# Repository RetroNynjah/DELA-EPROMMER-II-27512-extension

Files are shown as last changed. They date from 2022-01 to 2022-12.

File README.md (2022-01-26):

# DELA-EPROMMER-II 27512 Extension
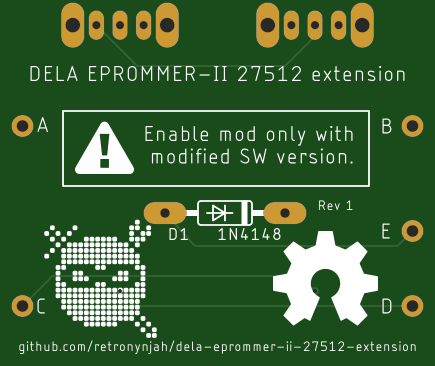
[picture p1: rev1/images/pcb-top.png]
PCB


## Background 
This is a reproduction of the 27512 extension board from DELA-Elektronik for the DELA-EPROMMER II for the Commodore 64.  
The user instruction calls this add-on "Umbauset für den DELA-EPROMMER II"

This extension makes it possible to program 27512 EPROMS with the DELA-EPROMMER II by removing VPP from pin 1 and replacing it with the switch controlled address pin A15. A special version of the DELA EPROMMER software is needed which connects VPP to pin 22. This special version is available in the software folder.
The 27512 has to be programmed in two 32kB passes and there are two switches on the board, one for activation/deactivation of the extension and one for 32kB block selection (A15).

When this extension is active, the EPROMMER should only be used with a special version of the DELA EPROMMER software. If the extension is deactivated by the switch, it can be used with the standard software.
A scan of the orginal German user manual for the extension was posted in [this forum thread](https://www.forum64.de/index.php?thread/109845-dela-ii-brenner-mit-zusatzplatine/). There's also a copy in the docs folder.

## Installation instruction
Follow the german user instruction in the docs folder or:

* Remove the diode that is located close to the ZIF socket and the LED. That diode is called D1 on Dirk's reproduction PCB.
* Solder points A,B,C,D on the extensions to the four corner pins of the ZIF socket on the bottom side of the board.
* Wire point E on the extension board to where the anode side of the diode was connected. See photos below or the original instruction in the docs folder.

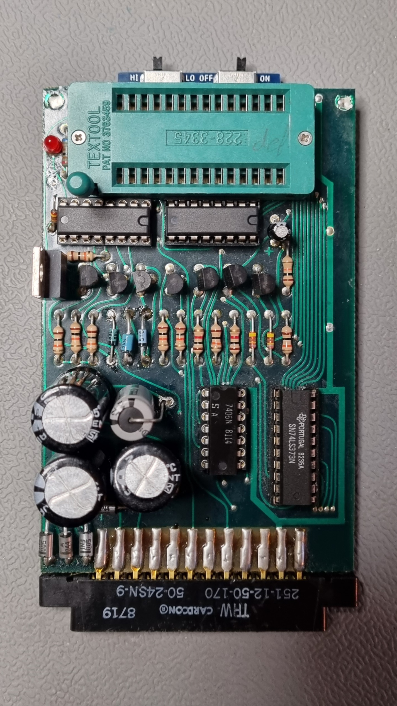
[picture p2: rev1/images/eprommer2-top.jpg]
top
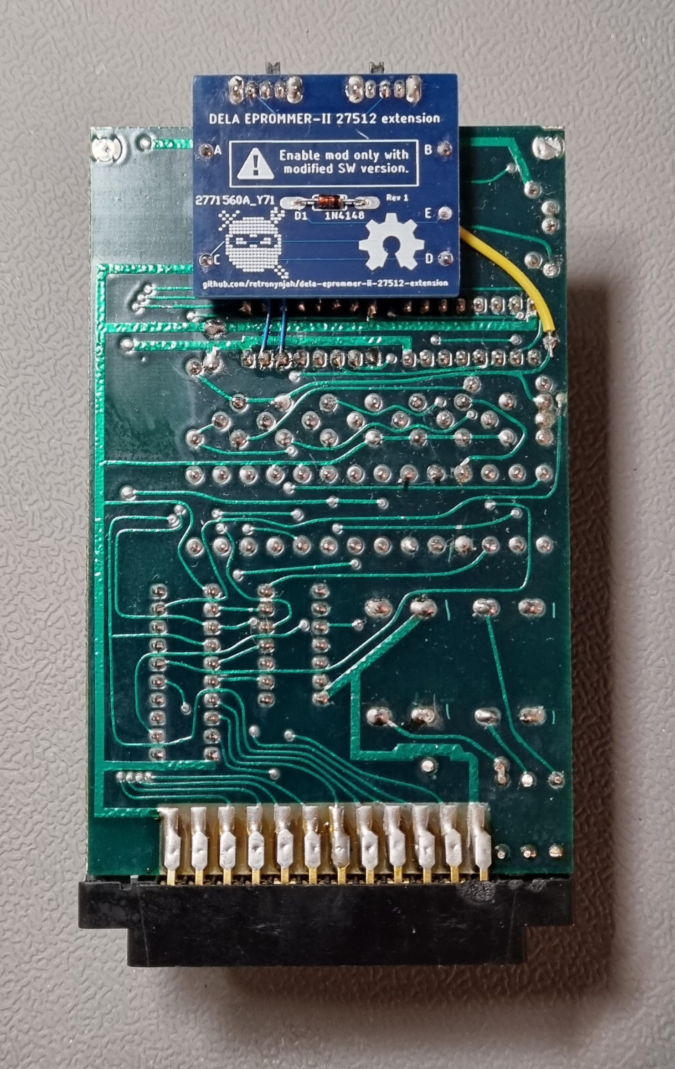
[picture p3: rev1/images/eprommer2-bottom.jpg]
bottom

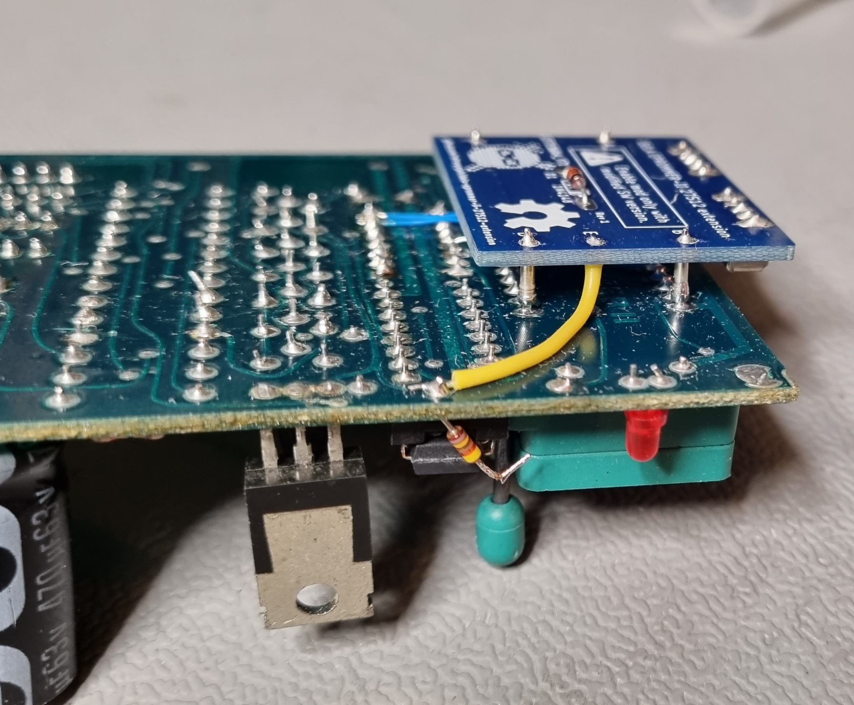
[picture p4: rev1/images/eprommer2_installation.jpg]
installation


The part count fort this build is low.
The two slide switches in the design are different from the ones on the original extension because silde switches with that pitch can't be found anymore.  
The ones I used are right-angle switches with a 2mm pitch and has solder connections for the metal frame to add stability. I used a cheap TE switch with part number 1825232-1 which can be found at Digikey with part number A107673-ND.  
The diode is a 1N4148.  
The posts that I use to connect the extension to the pins on bottom of the ZIF-socket are four pins that I pulled out of an IC socket with machined (round) pins. They can usually be grabbed with pliers and pushed out of the socket.

## Usage
**Warning!** Activate the exetension only together with the modified software.

The EPROM has to be programmed in two halved because a full 64kB EPROM image can't fit in RAM so you need to split your ROM file in two halves before programming.

To burn a 27512 EPROM:
* Activate the extension by setting the right switch to the ON position.
* Fire up the custom 512kbit version of the EPROMMER-II application
* Insert EPROM to be programmed.
* Load one half of the 64KByte ROM you want to program.
* Use the left slide switch to select which half you want to program
* Go into the EPROM programming menu and program as usual but select the invisible 6th option (27512) when selecting EPROM type.
* Repeat procedure for the next half of the EPROM

Dirk Wouters has created a reproduction of the complete DELA-EPROMMER II which together with schematics, user manuals and standard software can be found at https://github.com/DL2DW/DELA-EPROMMER-II

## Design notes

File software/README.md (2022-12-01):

# Software
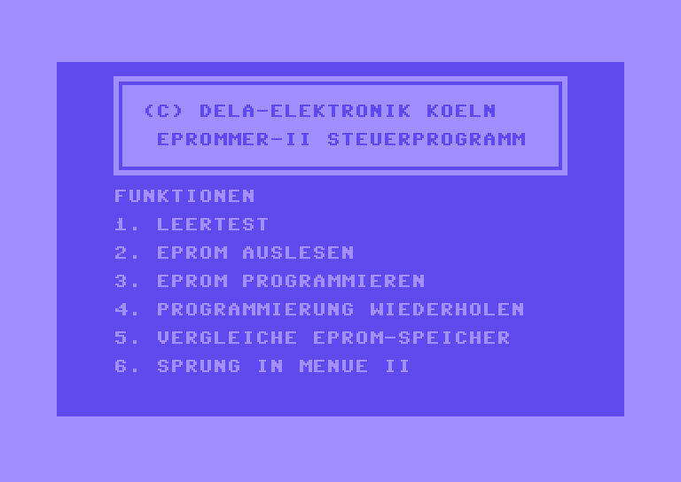
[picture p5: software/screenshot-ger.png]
PCB


This directory contains the original German version of the special 512kbit version of the EPROMMER software.

It also contains an archive with English versions translated by [giobbino](https://github.com/giobbino). Thank you!
The archive contains English translations of both the standard version of the software and the 512kbit version as well as translated user instructions. Everyone is welcome to improve the translations.

The English software along with some other tools now has an own repository at https://github.com/giobbino/DELA-Eprommer-II-ENG-software-for-Commodore-64

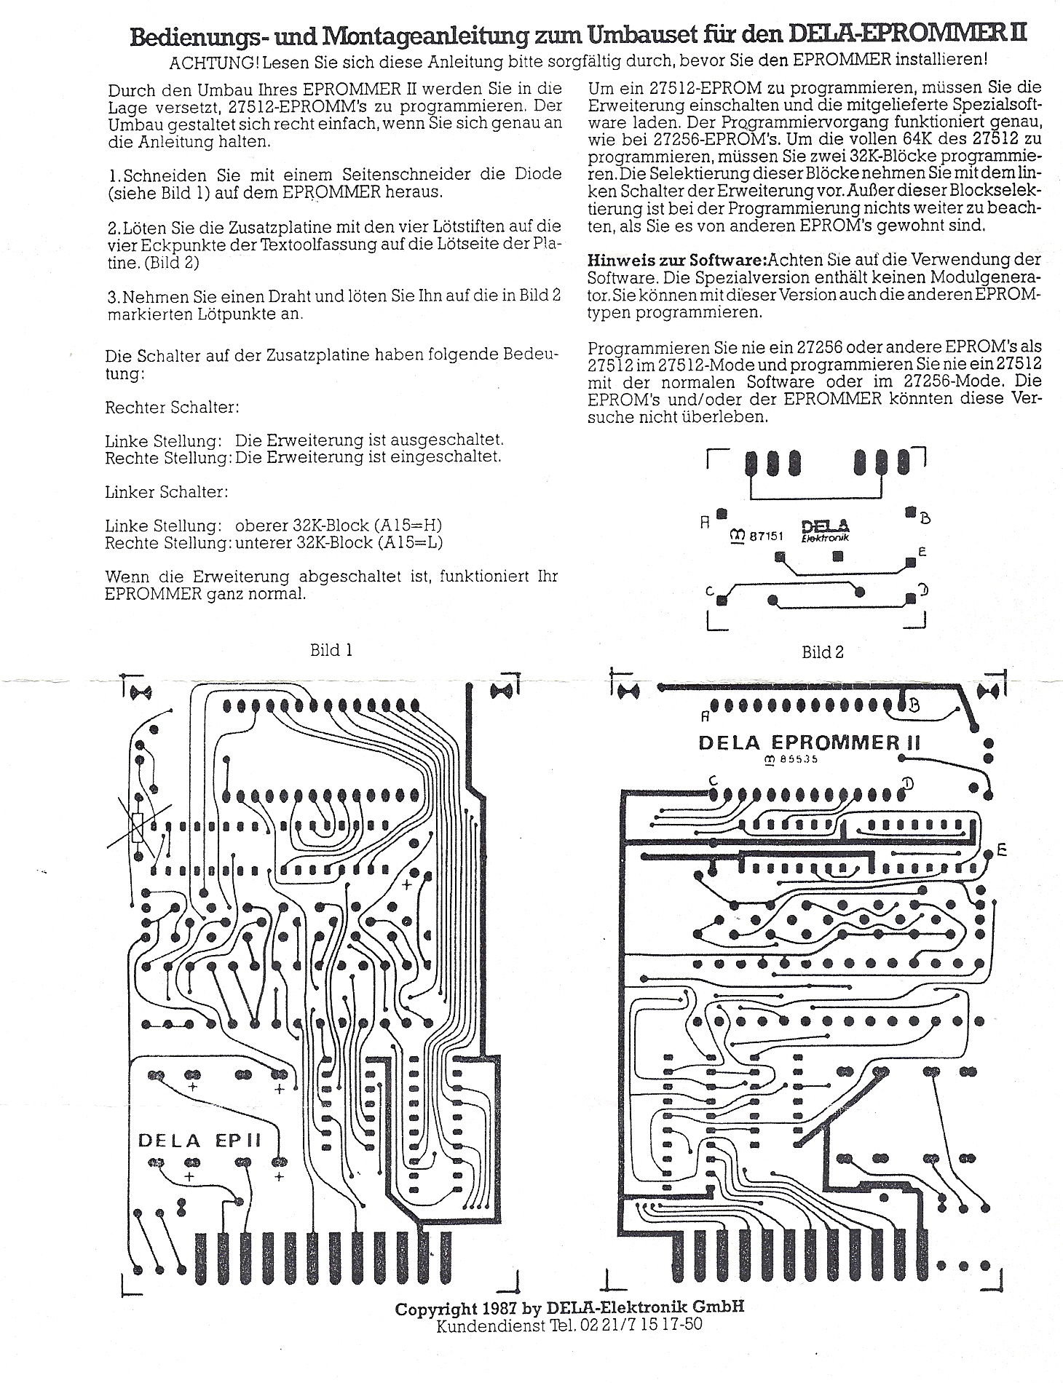
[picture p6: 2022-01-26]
docs/DELA2-Umbau512.jpg

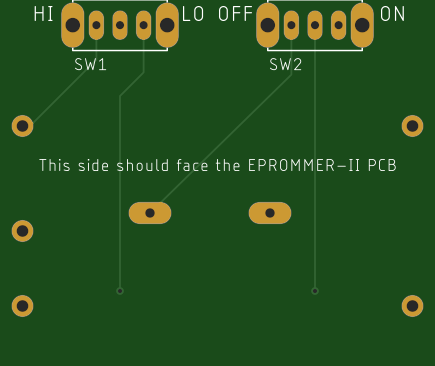
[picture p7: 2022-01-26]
rev1/images/pcb-bottom.png

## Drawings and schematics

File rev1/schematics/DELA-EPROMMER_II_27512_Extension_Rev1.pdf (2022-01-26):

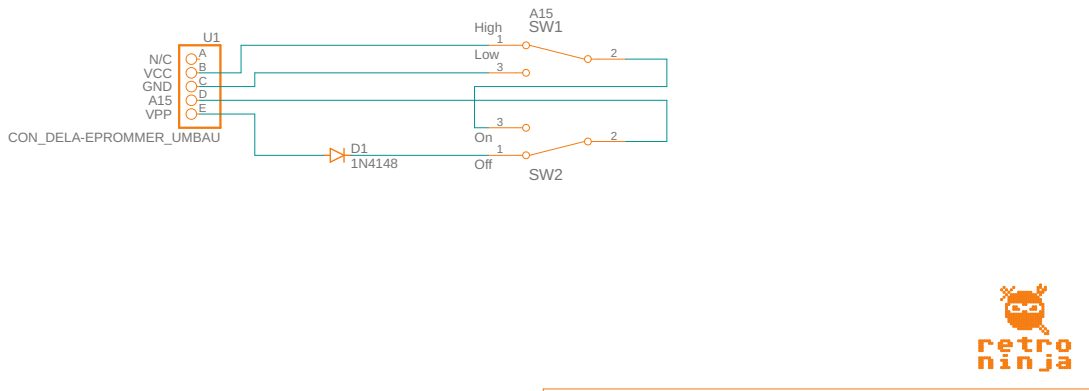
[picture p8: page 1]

DELA-EPROMMER II 27512 Extension

Document Number: | REV: 1

Date: 2021-12-23 | Sheet: 1/1

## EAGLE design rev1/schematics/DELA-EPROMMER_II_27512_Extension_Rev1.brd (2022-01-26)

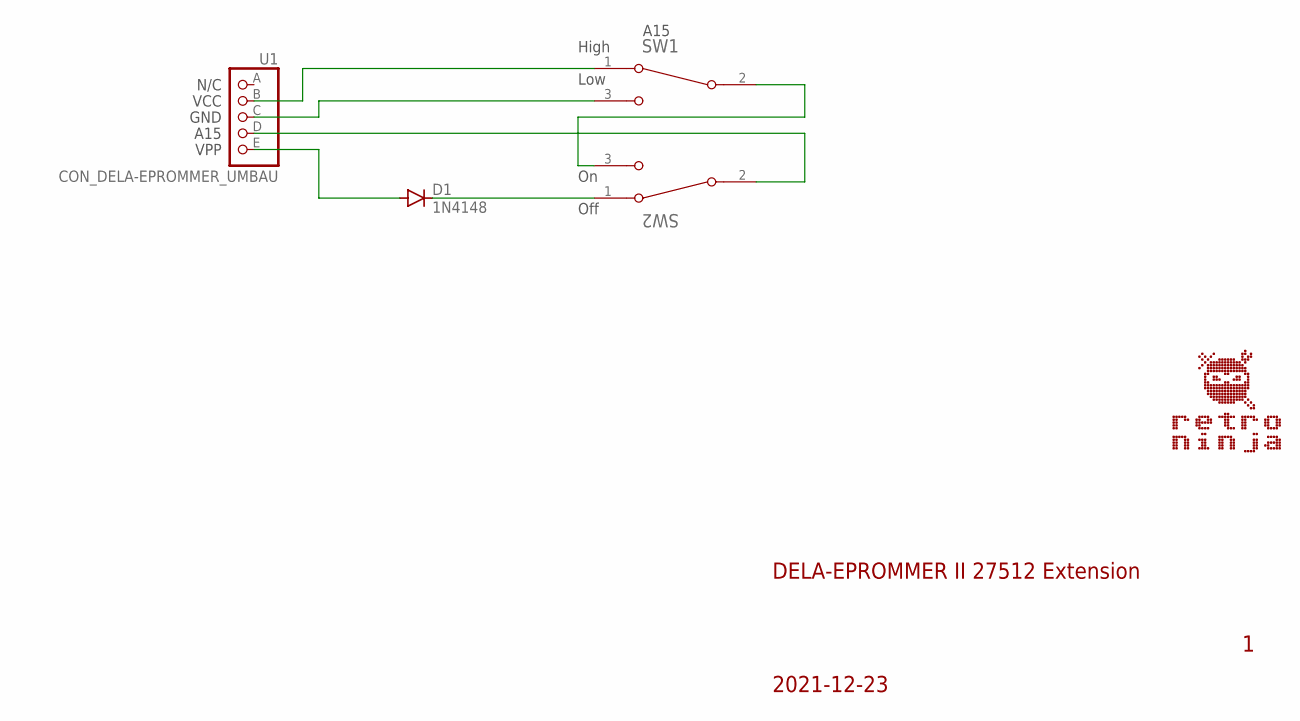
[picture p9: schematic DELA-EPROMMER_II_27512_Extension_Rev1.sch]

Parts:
D1: 1N4148; DO35-10
SW1, SW2: SWITCH_SLIDE_2POS_2MM
U1: CON_DELA-EPROMMER_UMBAU

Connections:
unnamed: SW1.1, U1.B
unnamed: SW1.3, U1.C
unnamed: SW2.2, U1.D
unnamed: SW1.2, SW2.3
unnamed: D1.C, SW2.1
unnamed: D1.A, U1.E

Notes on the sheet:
N/C
VCC
GND
A15
VPP
High
Low
Off
2021-12-23
DELA-EPROMMER II 27512 Extension

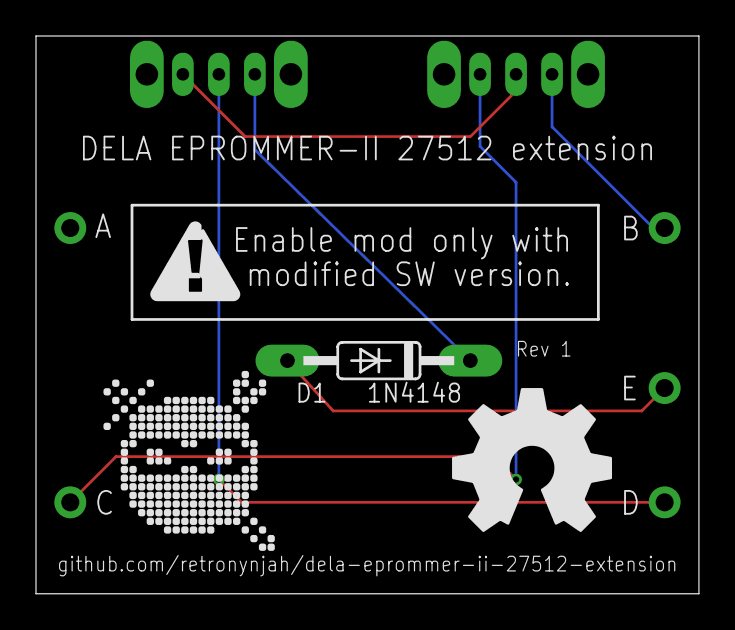
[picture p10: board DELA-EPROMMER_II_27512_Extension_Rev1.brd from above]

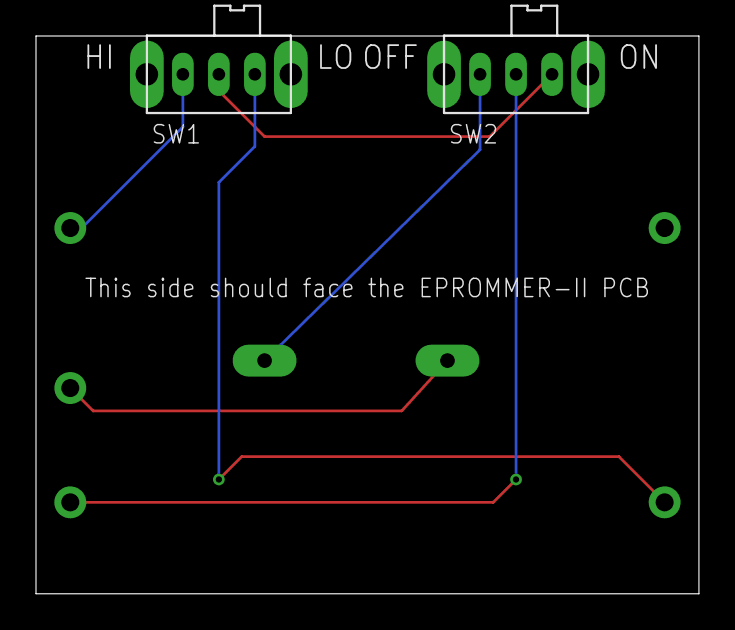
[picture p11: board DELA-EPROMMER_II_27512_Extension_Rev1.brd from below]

Board: 2 copper layers, 36.8 x 31.0 mm, 7 parts (2 on the bottom side), 6 nets.

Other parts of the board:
U$1: WARNING_5MM
U$2: RETRONINJA_NOTEXT_10MM
U$3: OSHW_NOTEXT_8MM

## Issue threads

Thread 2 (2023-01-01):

a question related with the DELA eprommer

giobbino, 2023-01-01:
Hello,
I've built your adapter. But I have an issue with the eprommer that prevent me to use both the eprommer and the eprommer with the 512k extension.
I know that you have nothing to do with the eprommer redesign, but you're the only one person I can ask help...

I built the [https://github.com/Commodore-Bench/DELA-EPROMMER-II](https://github.com/Commodore-Bench/DELA-EPROMMER-II) project but I'm experienced corrupted / scrambled data when I try to read an EPROM. Unfortunately this project doesn't allow issues and I don't know how to contact the owner.

I have the following issue:

If I compare the EPROM I've just read with the memory content at $1000, most time it seems to be the same;
but when I get the save PRG from the disk, remove the two first bytes (loading address) and compare it with the original BIN, the content is all scrambled / different. I've discovered the content is saved in blocks that are in different location respect the original BIN file (i.e. $0800 to $0FFF is saved at $1800 to $, etc.)

I've built three of them (just to be sure it wasn't my issue in the assembling process)...
I tried to replace all the ICs using another from other sellers (the only parts in the board that came from the same seller are zener diodes and the transistors)....
I tested it with three different Commodore 64...
I tried to read a 27256 EPROM many times and saving it to disk, using both SD2IEC and real 1541 drive.....

RetroNynjah, 2023-01-01:
I have not used the redesign that Retrotinker did but I used his schematics for reparing two original Dela Eprommers.
I started a build of his redesign but never finished it. I noticed a problem with his design and that was that the voltage rating on at least one of the big electrolytic caps was too low so it was cooking. The one on the original board was higher than in his design.
Just checked my notes and it's CP3 that should be 63V. I had measured 49V over that capacitor on my boards.
My testing of his board stopped there so I don't know if there's more errors in his design. Unfortunately his gone from Github and doesn't respond to email.

I've used my adapter with original boards from Dela and it works with them.

giobbino, 2023-01-01:
Thank you for your prompt answer.
I will check that cap (I used a 35v model; it didn't explode but it could be damaged).

Did you plan to finish the redesign of the DELA eprommer?

RetroNynjah, 2023-01-01:
I hadn't planned too. I completely forgot about that build. Perhaps I can find some time to replace the cap and try to dump some ROMs and see if it works any different than the original hardware.

giobbino, 2023-01-01:
I will try to replace the cap with one of the suggested voltage and see what happen.
Can you confirm me that you can successfully save and load the EPROM images with the original DELA eprommer?

giobbino, 2023-01-01:
...I replaced the CP3 capacitor with a 100v one. No changes.
The board behavior is really weird:
- read a 2756 eprom at $1000
- compare the eprom content with the memory content at $1000: no error messages (it simply returns to the main menu)
- write another 27256 eprom with the memory content starting at $1000 - no error messages (the write routine compares the eprom content with the memory content at every written byte and returns a message in case of error, so I assume the write process is ok)
- compare the new eprom content with the memory content at $1000: no error messages

-- compare the two eproms content with my MiniPro programmer: **the content of the new eprom is scrambled!**

I don't understand what's going on, I also wondered if my eng-translated version could have some issue, so I tried the original german version. No way.

So, here it comes my latest question: admitting just for a moment the hardware is ok _(and assuming that probably it isn't)_, could it be a wrong software version? I mean, is there another software version suitable for that board? Because I don't understand how the software doesn't identify that the RAM content is different from the eprom...

RetroNynjah, 2023-01-02:
I don't understand it either.
I dug out my original DELA eprommers but I can't even get them to read a 27256 EPROM realiably using the original German version (non-512kbit). It somehow managed to read an AT27C256R OTP EPROM almost correct. There were a few sections of incorrect bytes though so I thought I should try an older UV-erasable AM27256 in case it was an compatibility issue but that one only returned a few correct blocks.
It somehow managed to fry a few of my AM27256 EPROMs during my tests so I'm giving up on this. I don't have enough EPROMs that I can waste on troubleshooting it.

giobbino, 2023-01-02:
Wow, it fried the EPROMs? Weird, indeed.  At least mine didn't burn anything...
Well, thank you very much for your help, I really appreciated your effort and support.
Since I've built the eprommer for fun, I think it's time to give up. The MiniPro does its job quite well and I don't need the eprommer, actually LOL
